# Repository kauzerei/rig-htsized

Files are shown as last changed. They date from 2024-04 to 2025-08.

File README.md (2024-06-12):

# Htsized Rig
Customizable 3d-printable parts for building RigHtsized camera Rig.

Build the cage tailored to your particular camera.
Doesn't matter if it's too old, too new or too obscure for existing cage to be available.
Follow any cinema standard, or not, the customizeable models are not here to judge.
You may use the rods of any diameter you want or already have lying around.
The camera may be any distance from the rods.
The parts can be as thin or as thick as you like.

### File tree structure:
'cameras' - 3d-scans of digital cameras used to generate cages.

'scad' - OpenSCAD models of parts

'scad/include' - External files used in some of the models.
Some are written by me, some copied from Internet.
See the contents of files to find the source.

'drafts' - OpenSCAD models that are kinda offtopic, but still somewhat fit here. 
Some are too specific for random pieces of equipment I own.
Some are designed but not used in the context of my rigs.

'stl_export' - stl files generated from the models. Not necessarily from the latest version of models
It's beter if you generate them from models, but I'll keep them also here for now.

## Rightsized cage
The idea is to use a 3d-model of a camera (for example by 3d-scanning it using photogrammetry) and helper functions to define the perfect shape of a cage, that fits specifically your camera and your vision of comfort.

'cage.scad' contains coordinate-visualization tools to help designing and modules that help generating the part.

'cage_sony_nex_f3.scad' and 'cage_olympus_e-pm1.scad' are cages for particular cameras, made with those tools.

## Rightsized rod nounts
Clamps and other parts to build the rail system and to mount things on it.

Skewed parts with offset holes allow to have access to all screws from one side without collisions.
For example, you can mount the spacers to the bottom of the cage, then the rail system to the bottom of spacers, while still maintaining acces to the screws holding the cage.

## Rightsized grips
Ergonomic handles, that fit user's hands.

The idea is to sculpt a handle out of some modelling material, take some measurements and use them to generate tailored 3d-printable smooth grips.

The full description of the process is to be written, but in short it looks like this:

Take a piece of modelling putty about 100mm high, 30mm wide and about 40mm in the third dimension.

Press it slightly inside your hand to feel more comfortable.

Round its edges, and reshape it a little to be of the same height and width as initially.

Repeat the process several times, making it more comfortable to hold with each iteration while constraining its shape to something oblong in horizontal cross-section, constant width and without sharp edges.

Measure coordinates of key points (edges, high and low points, etc) of the shape using caliper, photograph or scan of the object in image editor and put them into array, the OpenSCAD module reconstructs the surface from them.

## Rightsized plate
Manfrotto-501-style tripod plate with hole raster.
Those plates are used in multiple tripods and stabilized gimbals.
They may slightly differ from original Manfrotto design, that's why the model is fully customizable.
You can change width and height of the mechanical features to fit the shape of your gear, try on shorter length to save material.
You can change the length to fit the amount of your gear: use longer plate if you use wide range of lens/accessories masses to always be able to slide the plate in tripod/stab to find balance without unscrewing the plate from the camera.

## Battery holder
Mount 18650 batteries to the camera cage.
Power any other equipment from the same easily swappable power source.

## Arm
Arm for mounting something some distance from the rod.
Used for mounting the monitor to an additional rod.
Take it with caution as work in progress.

## Rosette
Use cinema standard hirth joint to mount something at an adjustable angle.
Compatible with existing grips, monitor mounts, etc.

## Cokin adapter
Mounts the Cokin Series P filter holder to the rails.
Use Cokin Series P accessories as a matte box.

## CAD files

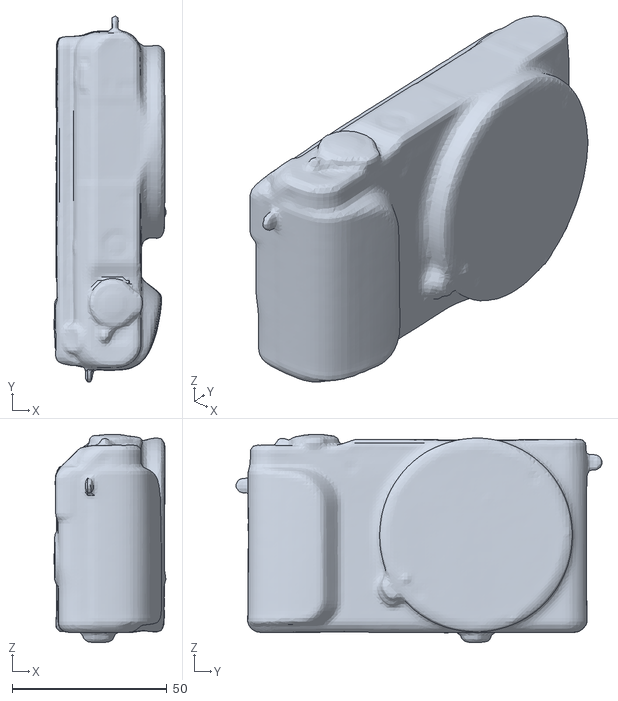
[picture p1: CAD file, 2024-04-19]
cameras/Sony_NEX-F3.stl
36.2 x 118.4 x 67.3

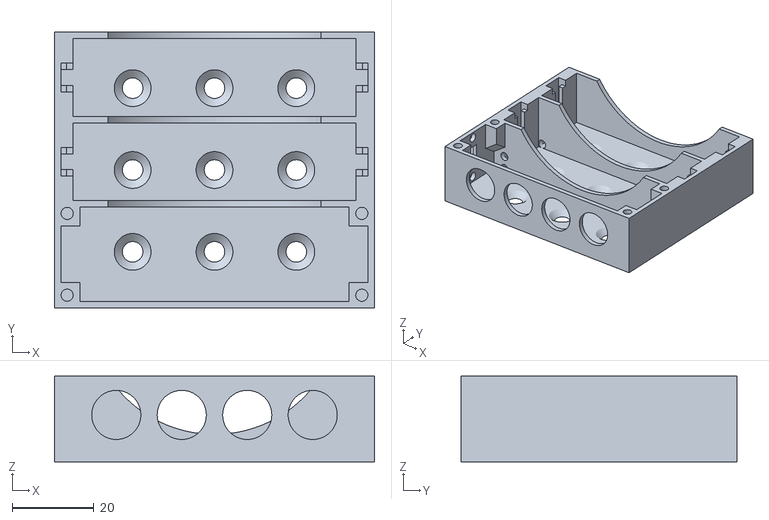
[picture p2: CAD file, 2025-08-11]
stl_export/battery_holder.stl
78.2 x 67.4 x 21.0

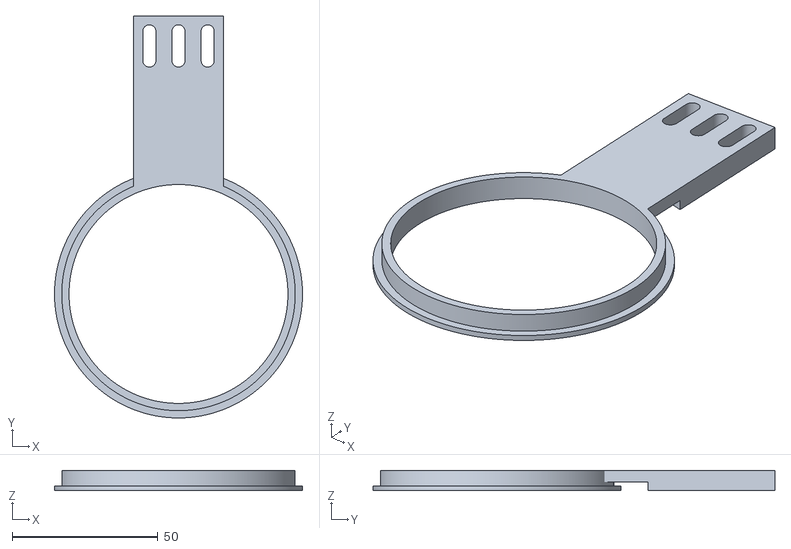
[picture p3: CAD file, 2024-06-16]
stl_export/cokin_adapter.stl
85.0 x 137.8 x 7.00

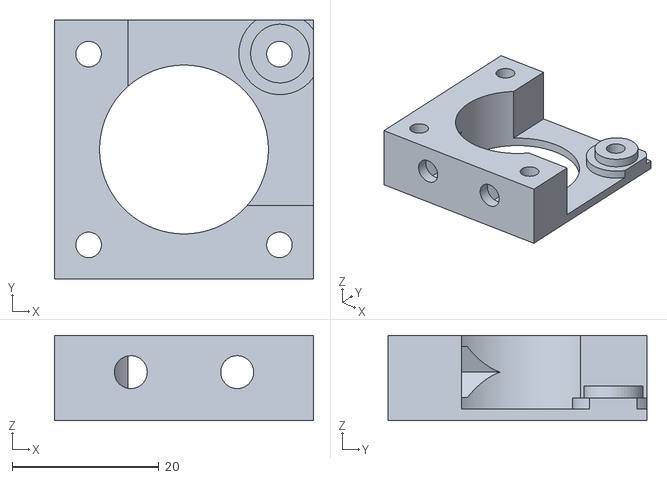
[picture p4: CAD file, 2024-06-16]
stl_export/motorized_focus_motor_bracket.stl
35.3 x 35.3 x 11.6

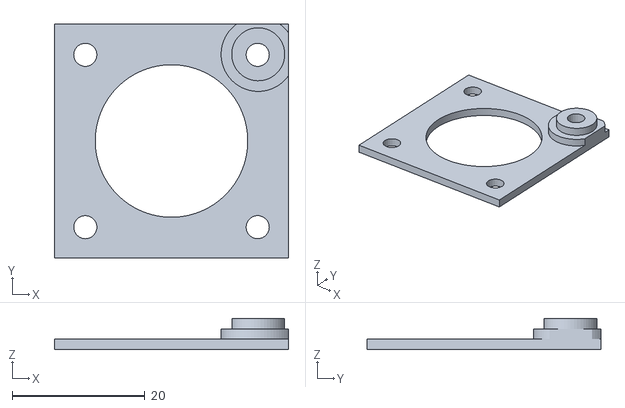
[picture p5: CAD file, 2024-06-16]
stl_export/motorized_focus_motor_cover.stl
35.3 x 35.3 x 4.70

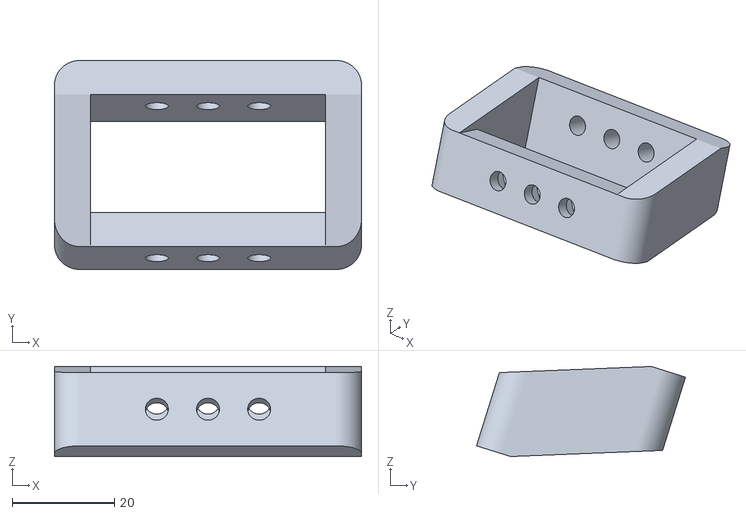
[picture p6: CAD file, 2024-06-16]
stl_export/spacer.stl
60.0 x 40.9 x 17.6

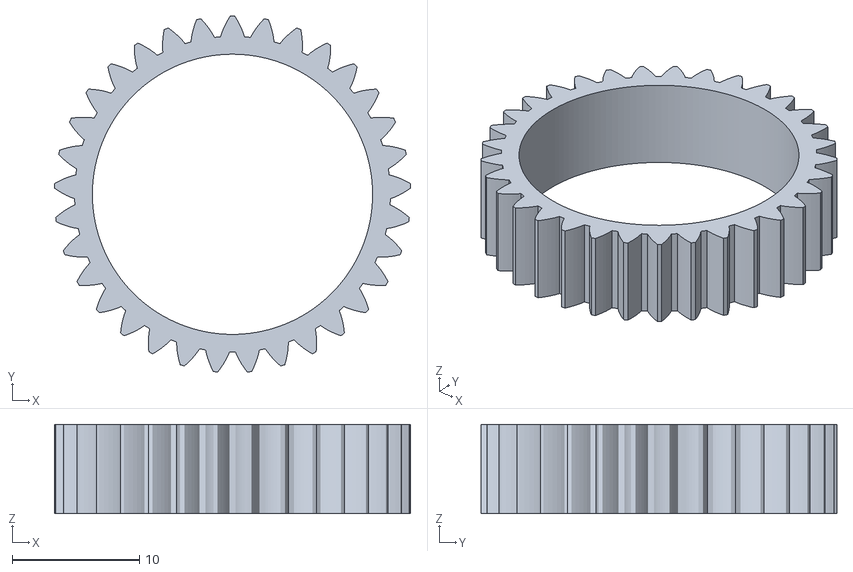
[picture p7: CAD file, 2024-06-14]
stl_export/motorized_focus_external_gear.stl
28.0 x 28.0 x 7.00

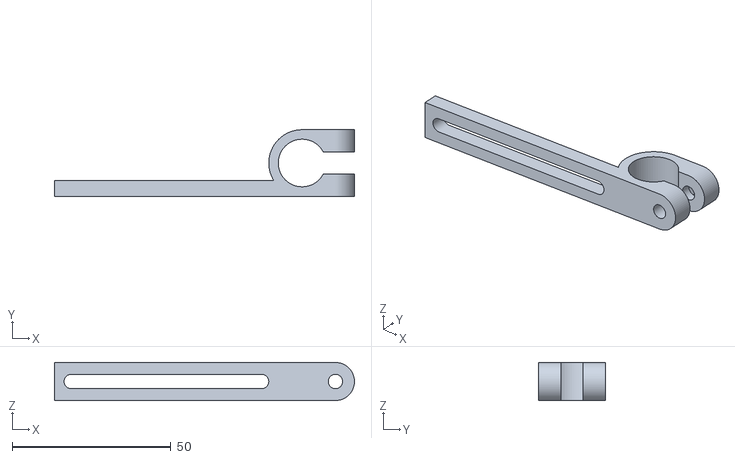
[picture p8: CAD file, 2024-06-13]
stl_export/rod_mounts_motor_mount.stl
94.5 x 21.0 x 12.0

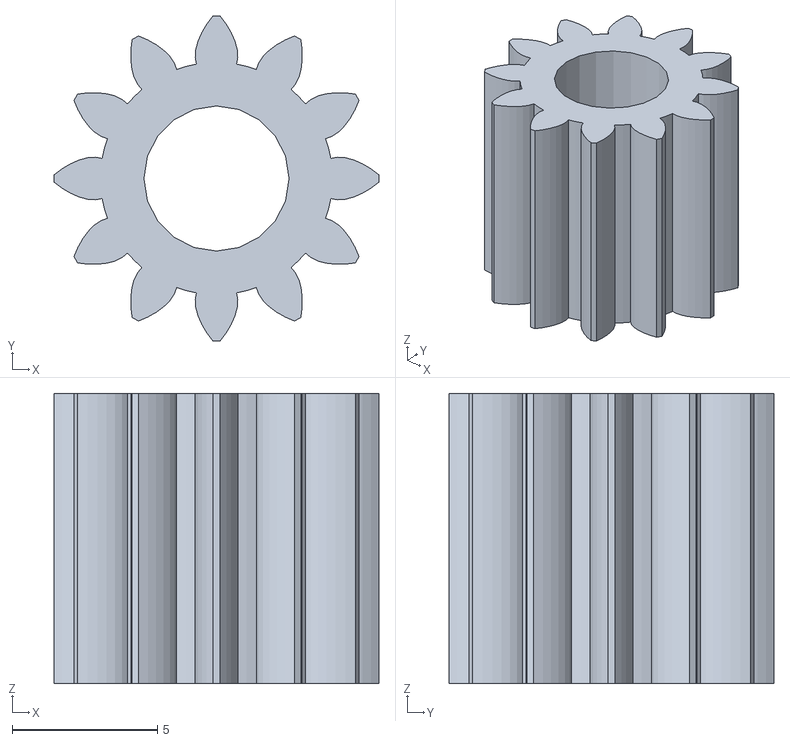
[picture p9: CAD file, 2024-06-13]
stl_export/motorized_focus_motor_gear.stl
11.2 x 11.2 x 10.0

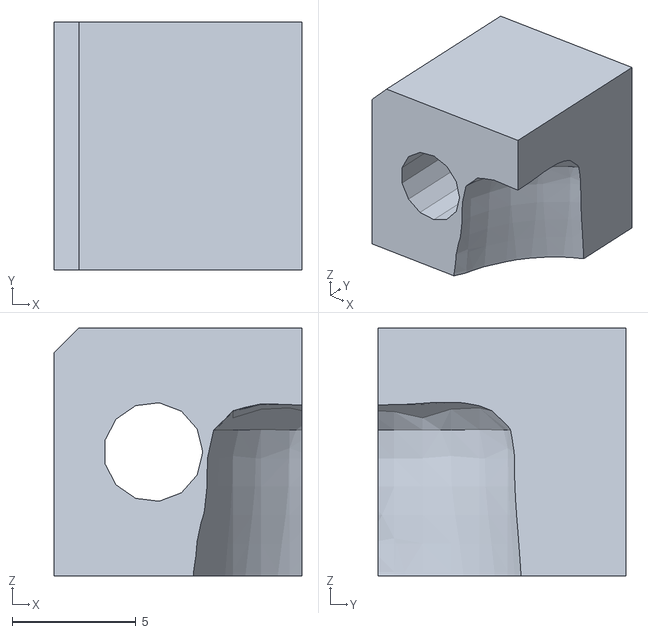
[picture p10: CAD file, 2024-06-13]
stl_export/corner1.stl
10.0 x 10.0 x 10.0

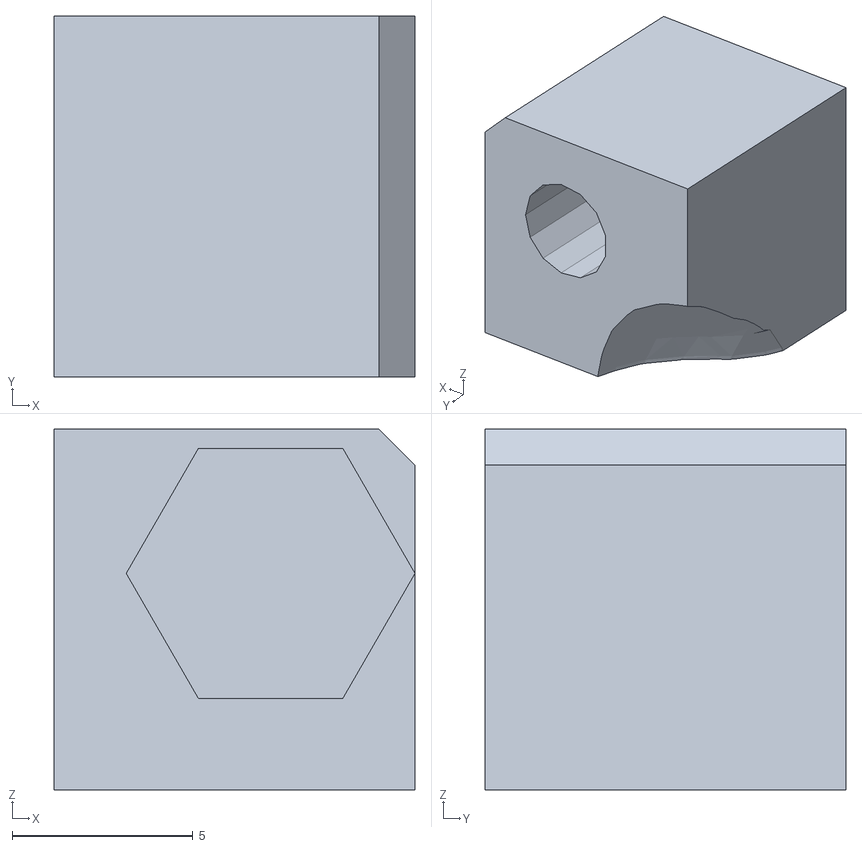
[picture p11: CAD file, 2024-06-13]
stl_export/corner4.stl
10.0 x 10.0 x 10.0

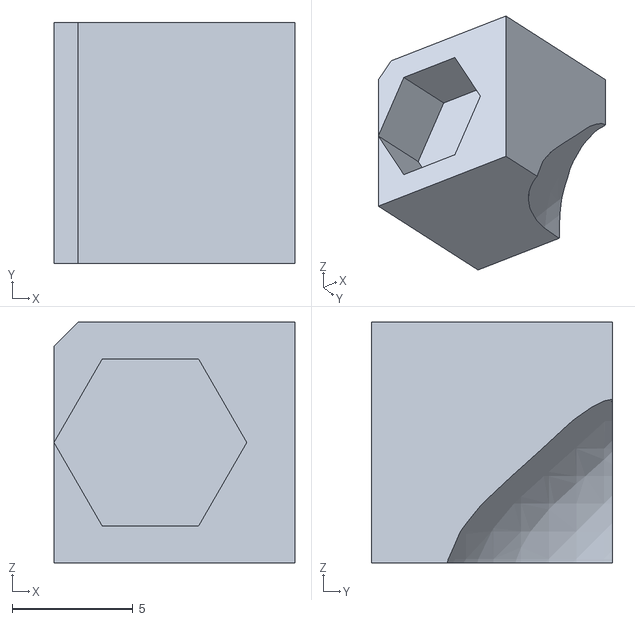
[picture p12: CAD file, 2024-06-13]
stl_export/corner3.stl
10.0 x 10.0 x 10.0

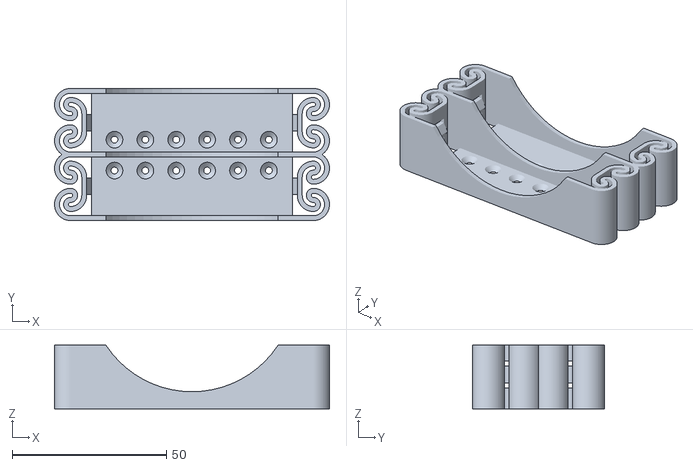
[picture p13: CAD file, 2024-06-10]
stl_export/sony-np-f-battery_springed_holder.stl
89.1 x 42.8 x 20.6

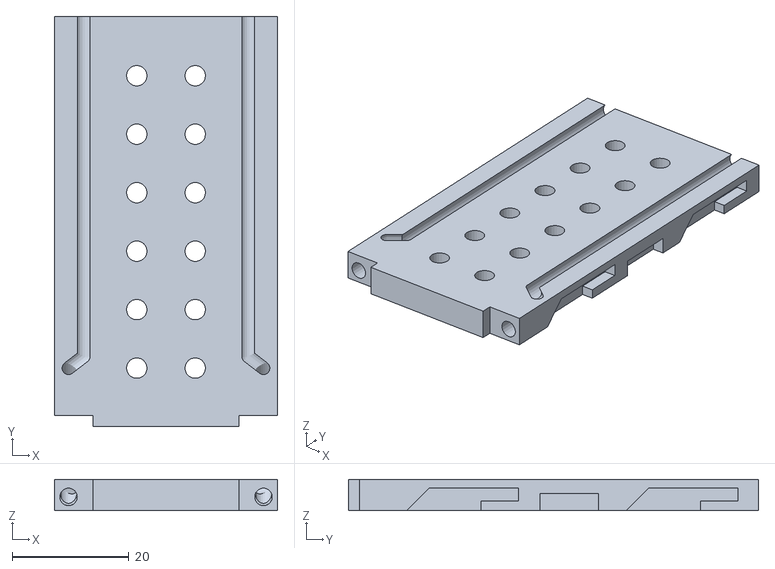
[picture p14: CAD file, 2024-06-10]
stl_export/sony-np-f-adapter.stl
38.1 x 70.1 x 5.35

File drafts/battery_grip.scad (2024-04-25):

// Generating battery grips for cameras, that aren't supposed to have ones.
// camera() is the camera standing on XY-plane with tripod screw centered.
// battery_door() is the shape of the door open at a certain angle.
// battery_protrusion() should make contact with camera as if there's no door.

$fa = 1 / 1;
$fs = 1 / 1;
//$fn = 16;
radius = 1;
step = 1;
border = 6;
height = 5;
air = 1;
chamfer = true;

module cs() {
  render() projection(cut = true) translate([ 0, 0, -border ]) camera();
}

module camera() { translate([ -1, -12, 0 ]) import("eos_10_lr.stl"); }

module battery_door(rotated = 0) {
  translate([ 12, -67, 3 ]) rotate([ 0, 0, 135 ]) rotate([ 0, -rotated, 0 ])
      hull() {
    translate([ -12, -8.7, -1 ]) cylinder(d = 19, h = 4, center = true);
    translate([ -12, 8.7, -1 ]) cylinder(d = 19, h = 4, center = true);
  }
}

module battery_protrusion() {
  translate([ 12, -67, 0 ]) rotate([ 0, 0, 135 ]) {
    translate([ -12, -8.7, 0 ]) cylinder(d = 16, h = 40);
    translate([ -12, 8.7, 0 ]) cylinder(d = 16, h = 40);
    translate([ -18, -9, 0 ]) cube([ 14, 18, 40 ]);
  }
}

module space_for_door(angle = 45, travel = 30, precision = 10) {
  minkowski($fn = 16) {
    battery_door(angle);
    translate([ 0, 0, -air ]) cylinder(h = travel, r = air);
  }
}

module space_for_battery() { translate([ -40, -5, -20 ]) cube([ 70, 20, 21 ]); }

module complete_grip() {
  difference() {
    union() {
      battery_protrusion();
      grip_body();
    }
    space_for_door();
    translate([ 0, 0, -height ]) cylinder(d = 25.4 / 4, h = 2 * height);
  }
}

module grip_body() {
  difference() {
    minkowski() {
      translate([ 0, 0, -height + radius ]) render()
          linear_extrude(height = height - radius + border - air, convexity = 4)
              offset(r = -radius) cs();
      intersection() {
        if (chamfer)
          translate([ 0, 0, -radius ])
              cylinder(r1 = 0, r2 = radius + air, h = radius);
        else {
          sphere(r = radius, $fn = 16);
          translate([ -radius, -radius, -radius ])
              cube([ 2 * radius, 2 * radius, radius ]);
        }
      }
    }
    camera();
  }
}
complete_grip();
*camera();
*battery_door();
*battery_protrusion();

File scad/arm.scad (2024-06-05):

// Arm with rosette mount on one side and tube mount on the other
// For mounting monitor on the tube parallel to it

$fa = 1 / 1;
$fs = 1 / 2;
d_tube = 16;
wall = 3;
hole_d = 4.5;
nut_d = 9;
bolt_offset = 30;
mount_offset = 50;
part_width = 10;
raster = 10;
bissl = 1 / 100;
alot = 200;

module hole(hole_d=hole_d, nut_d=nut_d, wall = wall, depth = depth) {
  translate([ 0, 0, -bissl ]) cylinder(d = hole_d, h = alot);
  translate([ 0, 0, -bissl ]) cylinder(d = nut_d, h = wall - depth, $fn = 6);
}

module arm() {
  difference() {
    union() {
      translate([ -mount_offset + wall + d_tube / 2, 0, 0 ]) rotate([ 0, 0, 0 ])
          cylinder(h = part_width, d = 2 * raster + 2 * hole_d + wall,
                   center = true);
      hull() {
        translate([ d_tube / 2 + wall, 0, 0 ])
            cylinder(h = part_width, d = d_tube + 2 * wall, center = true);
        translate([ -mount_offset + wall + d_tube / 2, 0, 0 ])
            rotate([ 0, 0, 0 ])
                cylinder(h = part_width, d = d_tube + 2 * wall, center = true);
      }
    }
    translate([ d_tube / 2 + wall, 0, 0 ])
        cylinder(h = part_width + bissl, d = d_tube, center = true);
    translate([ 0, 0, 0 ]) rotate([ 90, 0, 0 ])
        cylinder(h = d_tube + 2 * wall + bissl, d = hole_d, center = true);
    translate([ 0, -d_tube / 2, 0 ]) rotate([ 90, 0, 0 ])
        cylinder(h = d_tube + 2 * wall + bissl, d = nut_d, $fn = 6);
    translate([ -mount_offset + wall + d_tube / 2, 0, 0 ])
        rosette_mount_holes(wall = part_width, depth = wall, raster = raster);
    hull() {
      translate([ -mount_offset + wall + d_tube + d_tube / 2, 0, 0 ]) cylinder(
          h = part_width + bissl, d = d_tube - 2 * wall, center = true);
      translate([ d_tube / 2 + wall, 0, 0 ]) cylinder(
          h = part_width + bissl, d = d_tube - 2 * wall, center = true);
    }
  }
}

module rosette_mount_holes(wall = 10, depth = 2, raster = 10) {
  for (angle = [45:90:360])
    translate([ raster * cos(angle), raster * sin(angle), -part_width / 2 ])
        hole(wall = wall, depth = depth);
  translate([ 0, 0, -part_width / 2 ]) hole(wall = wall, depth = depth);
}

rotate([180,0,0])arm();

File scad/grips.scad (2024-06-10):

use<include/spline.scad>
function decimate(poly, m) =
    len(poly) < 3 ? poly
    : norm(poly[0] - poly[1]) < m
        ? decimate([ poly[0], for (i = [2:len(poly) - 1]) poly[i] ], m)
        : [ poly[0], each decimate([for (i = [1:len(poly) - 1]) poly[i]], m) ];
$fn = 64 / 1;
bissl = 1 / 100;
thickness = 30;
rosette_mount_length = 32;
rosette_mount_offset=30;
slot = 12;
nut_d = 9;
nut_h = 4;
wall = 3.2;
hole_d = 4.5;
part = "side_handle"; //[side_handle, tube_handle, handle_rosette_mount, handle_screw_washer]
module skew_extrude(list, d, reverse) {
  for (i = [0:len(list) - 2]) {
    startx = list[i][0];
    startz = list[i][1] + d * (reverse ? -1 : 1) / 2;
    h = list[i + 1][0] - list[i][0];
    shift = list[i + 1][1] - list[i][1];
    multmatrix(m = [[d, 0, shift, startz], [0, d, 0, 0], [0, 0, h, startx]]) {
      cylinder(d = 1, h = 1);
      translate([ reverse ? -10 : 0, -0.5, 0 ]) cube([ 10, 1, 1 ]);
    }
  }
}

module handle(front, back, thickness, reverse = false) {
  intersection() {
    skew_extrude(list = decimate(smooth(front, 6), 1), d = 30,
                 reverse = reverse);
    skew_extrude(list = decimate(smooth(back, 6), 1), d = 30,
                 reverse = !reverse);
  }
}

module side_handle() {
  front = [
    [ 0, -55 ], [ 15, -54 ], [ 26, -52 ], [ 38, -49 ], [ 48, -45 ], [ 60, -37 ],
    [ 73, -27 ], [ 86, -18 ], [ 101, -6 ], [ 107, 9 ]
  ];
  back = [
    [ 0, 11 ], [ 15, 9 ], [ 25, 21 ], [ 38, 19 ], [ 48, 30 ], [ 60, 28 ],
    [ 73, 38 ], [ 86, 36 ], [ 101, 47 ], [ 107, 47 ]
  ];
  difference() {
    handle(front, back, thickness);
    hull() for (tr = [ [ -31, 0, 10 ], [ 2, 0, 80 ] ]) translate(tr)
        rotate([ 90, 0, 0 ]) cylinder(d = hole_d, h = 31, center = true);
    hull() for (tr = [ [ -31, -1.6, 10 ], [ 2, -wall / 2, 80 ] ]) translate(tr)
        rotate([ 90, 0, 0 ]) cylinder(d = slot, h = 31);
    hull() for (tr = [ [ -31, 1.6, 10 ], [ 2, wall / 2, 80 ] ]) translate(tr)
        rotate([ -90, 0, 0 ]) cylinder(d = slot, h = 31);
  }
}

module handle_rosette_mount() {
  difference() {
    cube([ rosette_mount_length, slot - 1, rosette_mount_offset ]);
    for (tr = [ [ rosette_mount_length/2-10, (slot-1)/2, -bissl ], [ rosette_mount_length/2, (slot-1)/2, -bissl ], [ rosette_mount_length/2+10, (slot-1)/2, -bissl ] ])
      translate(tr) cylinder(d = hole_d, h = rosette_mount_offset + 2 * bissl);
    for (tr = [[ rosette_mount_length/2-10, (slot-1)/2, wall ],[rosette_mount_length/2+10, (slot-1)/2, wall]])
      translate(tr) cylinder(d = nut_d, h = rosette_mount_offset,$fn=6);
  }
}

module handle_screw_washer() {
  difference() {
    cube([slot - 1, rosette_mount_length, wall], center = true);
    cylinder(d = hole_d, h = wall + bissl, center = true);
  }
}

module tube_handle() {
  front = [
    [0, 17], [12, 12], [24, 15], [33, 14], [47, 19], [57, 17], [72, 22], [83, 20], [100, 25]                       
  ];
  back = [
    [0, -23], [12, -23], [25, -23], [33, -23], [47, -19], [57, -15], [72, -12], [83, -12], [100, -15]
  ];
  difference() {
    handle(back, front, thickness);
    translate([0, 0, wall]) cylinder(d = 16, h = 100);
    translate([0, 0, -bissl]) cylinder(d = hole_d, h = wall + 2 *bissl);
  }
}

if (part == "side_handle")
  side_handle();
if (part == "handle_rosette_mount")
  handle_rosette_mount();
if (part == "handle_screw_washer")
  handle_screw_washer();
if (part == "tube_handle")
  tube_handle();

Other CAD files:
stl_export/corner2.stl
stl_export/handle_rosette_mount.stl
stl_export/spacer36.stl
stl_export/cokin_mount.stl
scad/motorized_focus.scad
camera_rig_cage.scad
camera_rig_cage_sony.scad
drafts/matte_box_mount.scad
drafts/tube_coupler.scad
nice_cage.scad
rig.scad
scad/501_plate.scad
scad/battery_holder.scad
scad/battery_holder_old.scad
scad/cage.scad
scad/cage_olympus_e-pm1.scad
scad/cage_sony_nex-f3.scad
scad/cokin_adapter.scad
scad/include/battery_holder_double_spring.scad
scad/include/hirth.scad
scad/include/polyround.scad
scad/include/publicDomainGearV1.1.scad
scad/include/spline.scad
scad/rod_mounts.scad
scad/rosette.scad
stl_export/501_plate.stl
stl_export/arm.stl
stl_export/cage_olympus_e-pm1.stl
stl_export/cage_sony_nex-f3.stl
stl_export/handle_screw_washer.stl
stl_export/matte_box_clamp.stl
stl_export/matte_box_mount.stl
stl_export/spacer_block.stl
stl_export/tube_clamp.stl
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

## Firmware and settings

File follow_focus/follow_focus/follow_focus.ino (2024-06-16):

const char motor_step=2;
const char motor_dir=3;
const char encoder_a=4;
const char encoder_b=5;

void setup() {
  pinMode(motor_step,OUTPUT);
  pinMode(motor_dir,OUTPUT);
  pinMode(encoder_a,INPUT_PULLUP);
  pinMode(encoder_b,INPUT_PULLUP);
}

void loop() {
}

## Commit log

2023-06-17 start helper functions
    [rig.scad]
2023-06-18 arbitrary angle connector ready. With chamfer and fillet
    [rig.scad]
2023-06-18 chamfer and fillet no longer mixed up
    [rig.scad]
2024-04-14 add battery grip generator
    [bg.scad]
2024-04-16 olympus cage
    [camera_rig_cage.scad, camera_rig_cage.stl]
2024-04-19 start working on nicer cage
    [camera_rig_cage_sony.scad, fr.stl, lf.stl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]
2024-04-19 add round-anything file from official repo
    [polyround.scad]
2024-04-19 some cleanup
    [501_plate.scad, Sony_NEX-F3.stl, battery_grip.scad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]
2024-04-20 cage generalization
    [cage_olympus_e-pm1.scad]
2024-04-20 better abstraction
    [cage.scad, cage_olympus_e-pm1.scad]
2024-04-20 better shape for sony
    [cage_sony_nex-f3.scad]
2024-04-20 final edit before first print
    [cage_sony_nex-f3.scad, cage_sony_nex-f3.stl]
2024-04-23 better sony cage
    [cage_sony_nex-f3.scad, cage_sony_nex-f3.stl]
2024-04-24 start skewed clamp
    [universal_clamp.scad]
2024-04-24 skewed clamp ready-ish
    [rosette.scad, universal_clamp.scad]
2024-04-24 short arm
    [arm.scad, arm.stl, universal_clamp.stl]
2024-04-25 code lint
    [501_plate.scad, arm.scad, battery_grip.scad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]
2024-05-18 more than one cutout pro wall possible
    [501_plate.stl, arm.scad, arm.stl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]
2024-05-18 wire hole for sony, linting
    [cage_olympus_e-pm1.scad, cage_sony_nex-f3.scad]
2024-05-21 18650 holder
    [battery_holder.scad]
2024-05-31 start matte box mount
    [battery_holder.scad, battery_holder.stl, cokin_adapter.scad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]
2024-05-31 add better spacer
    [universal_clamp.scad]
2024-06-05 better (written) clamping system
    [rod_mounts.scad, spacer.stl, spacer36.stl]
2024-06-05 fixes is clamps
    [cokin_adapter.scad, matte_box_mount.scad, rod_mounts.scad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]
2024-06-05 variable name consistency
    [501_plate.scad, arm.scad, cage.scad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]
2024-06-05 code linting
    [cokin_adapter.scad, matte_box_mount.scad, rod_mounts.scad]
2024-06-06 more clamp types
    [battery_holder.scad, battery_holder_double_spring.scad, rod_mounts.scad]
2024-06-07 side handle
    [battery_holder_double_spring.scad, grips.scad, spline.scad]
2024-06-07 handle rosette mount
    [grips.scad, handle_rosette_mount.stl]
2024-06-10 cleanup in handles
    [battery_holder_double_spring.scad, grips.scad, handle_rosette_mount.stl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]
2024-06-12 corner pieces for sony cage
    [cage_sony_nex-f3.scad]
2024-06-12 making repo nicer
    [501_plate.scad, arm.scad, battery_holder.scad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]
2024-06-13 follow focus
    [cage_sony_nex-f3.scad, corner1.stl, corner2.stl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]
2024-06-13 follow focus clamp
    [motorized_focus_external_gear.stl, motorized_focus_motor_bracket.stl, motorized_focus_motor_cover.stl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]
2024-06-14 follow focus fixes
    [motorized_focus.scad, motorized_focus_external_gear.stl]
2024-06-16 straighten spacer
    [cokin_adapter.stl, motorized_focus_motor_bracket.stl, motorized_focus_motor_cover.stl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]
2024-06-16 arduino file
    [rosette.scad]
2025-05-27 working on power distribution
    [battery_holder.scad]
2025-06-10 new battery holder
    [battery_holder.scad, battery_holder_old.scad]
2025-06-10 holes for jacks and switch
    [battery_holder.scad]
2025-06-10 mount holes
    [battery_holder.scad]
2025-06-10 no magic numbers
    [battery_holder.scad]
2025-06-11 fix cable channeling
    [battery_holder.scad]
2025-08-11 from second laptop, no idea why
    [battery_holder.scad, battery_holder.stl]
2025-09-09 hole shape for jack recepticals
    [battery_holder.scad]
